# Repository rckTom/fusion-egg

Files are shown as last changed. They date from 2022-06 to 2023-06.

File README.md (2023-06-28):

# Fusion egg - An audioreactive festival totem

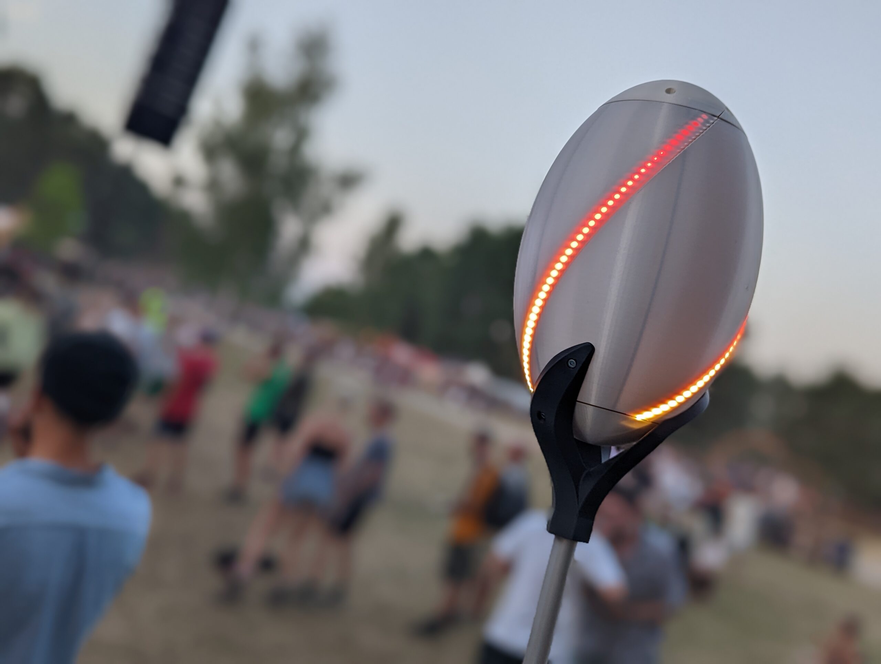
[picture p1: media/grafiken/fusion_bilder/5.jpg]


## Overview

This repository contains software and cad-files for an audioreactive festival totem. This totem is used to find ones crew at a music festival. It listens to the music, detects the beat and translates into a visual animation.

## Structure

## Build
To build your own totem you need the following tools:

- 3D-Printer (z-height min 250mm , Nozzle 0.8mm)
- Laser cutter to cut the internal skeleton of the egg
- Soldering iron

The following parts are needed:

- ESP32 microcontroller board
- Microphone MAX4466
- Accelerometer ADXL345
- WS2812 LED-Stripes (144 leds per meter), for the three stripe egg you need a little bit more than 1 meter. The six stripe egg requires more than 2 meters.
- USB-Powerbank
- Micro USB-Cabel
- Wago Connectors 221-415
- Cables
- Heat-shrink tubing
- Aluminium Tube (OD 20mm, ID 17mm, 2m long)
- 6 M4x20mm Screws
- 12 M4x15mm Screws
- 18 Heat-set inserts M4x6x6
- 3mm Plywood
- Two colors of PLA (light and dark color)
- Cable-ties

### 3D Printing
For the three stripe version you have to print the following files:
- cad_3stripes/vase.stl (Vase-Mode)
- cad_3stripes/boden.stl 
- cad_3stripes/deckel.stl
- cad_3stripes/klaue.stl

For the six stripe version the folling parts you need the files from the cad_6stripes folder.

### Laser-Cutting
cad_3stripes/lasercutter.pdf contains all parts you need to cut for the 3strip version. 

Assemble the parts with wood glue inside the vase printed part, as showed in this explosion diagramm:
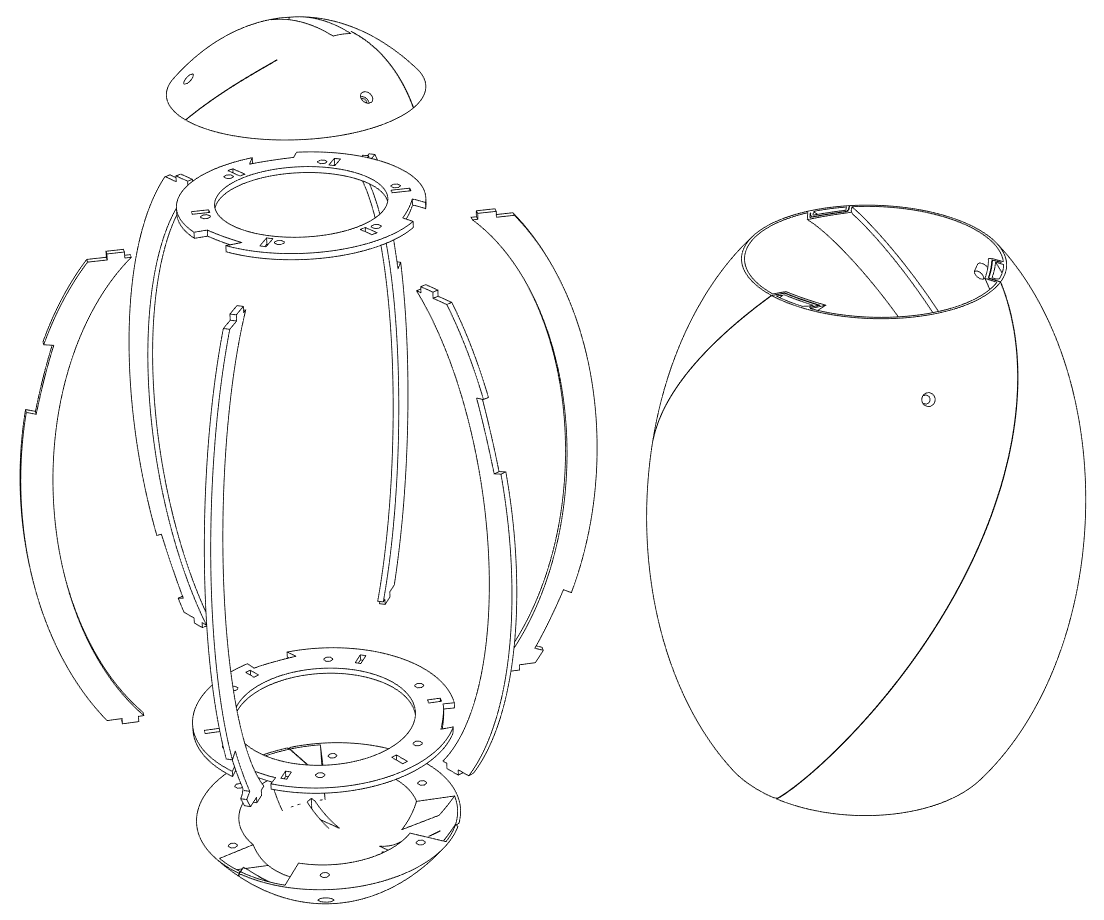
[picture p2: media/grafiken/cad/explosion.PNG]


### Electronics
Connect all electronics as showed here:
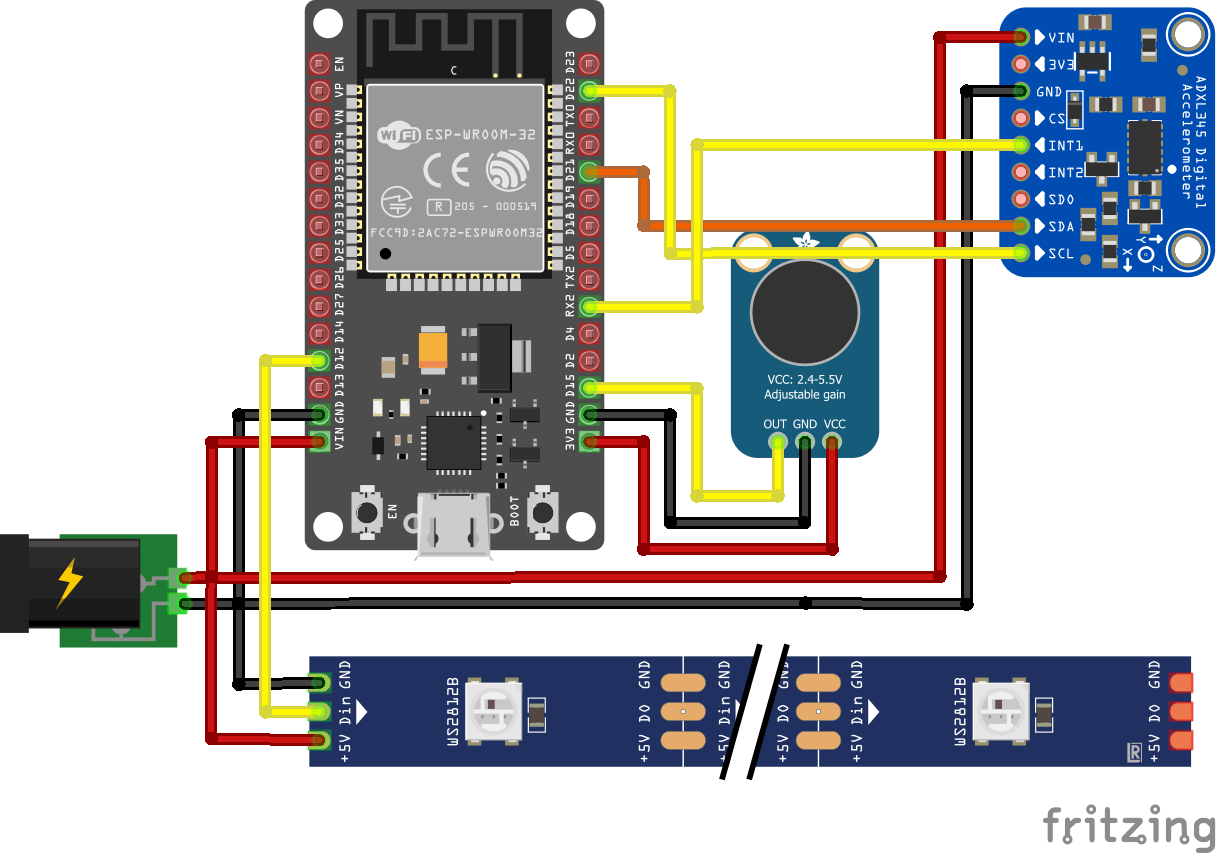
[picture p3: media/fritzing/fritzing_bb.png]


### Software
Build the sofware inside the firmware folder with PlatformIO. If you need to change the pin assignment for the leds or the microphone, you can find the definitions inside firmware/include/zauberstab.h. Don't forget to flash your eggs.

## License
All software is licensed under GPLv2. Hardware is licensed under CC BY-NC-SA. Contact us for commercial use.

## Contact
You can contact us at tom@binary-kitchen.de and buddhabrot@binary-kitchen.de

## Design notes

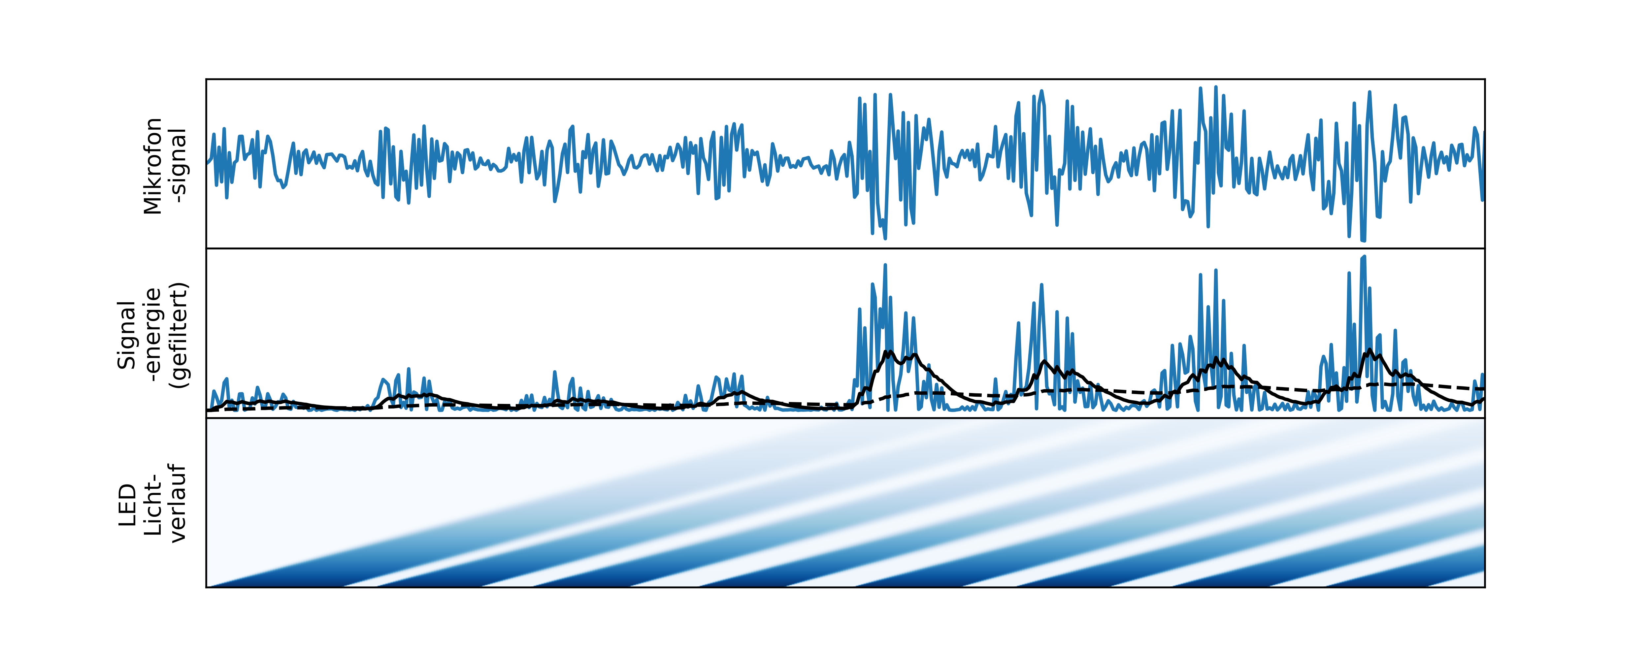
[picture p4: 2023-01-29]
media/grafiken/illustrationen/fackel.png

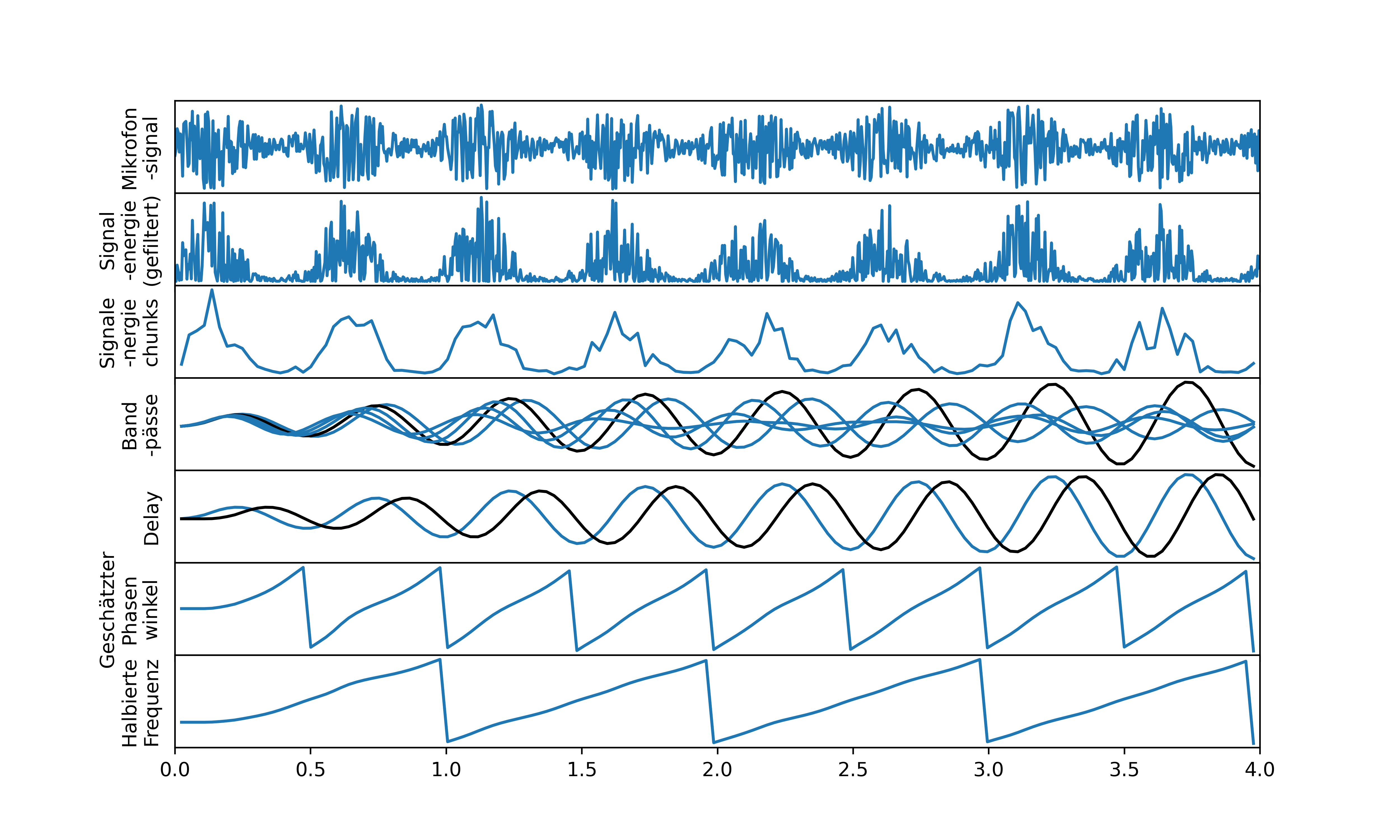
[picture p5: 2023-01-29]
media/grafiken/illustrationen/beaterkennung.PNG

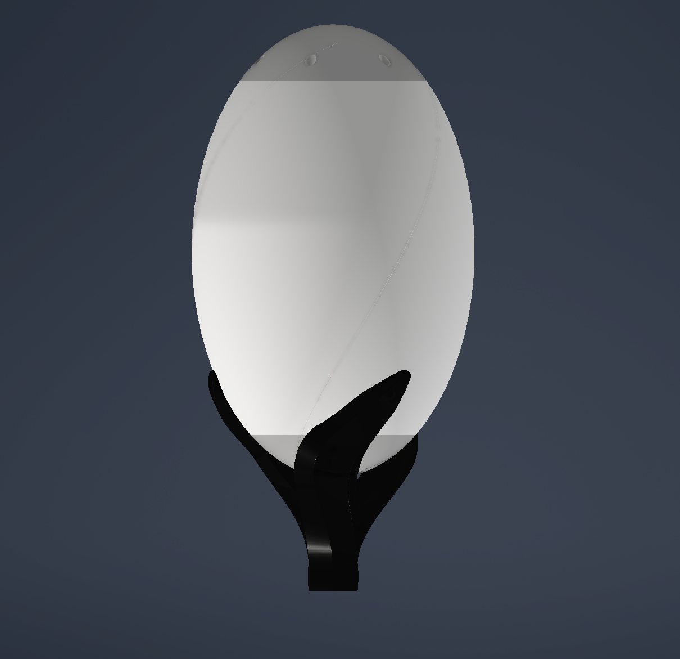
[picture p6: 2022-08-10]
media/grafiken/cad/zusammenbau3.PNG

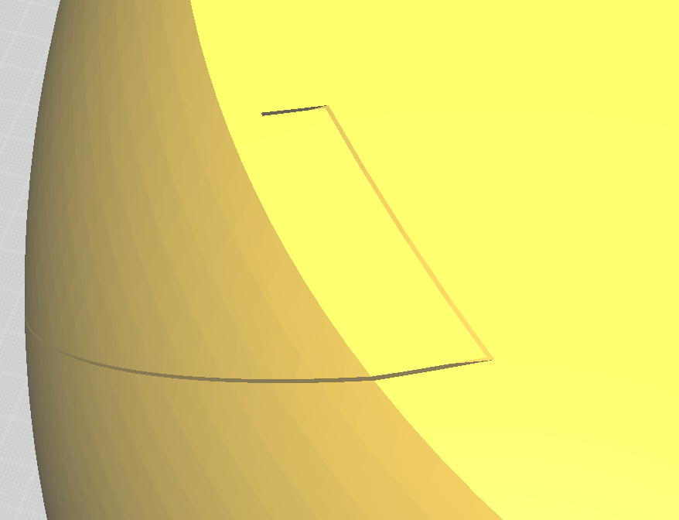
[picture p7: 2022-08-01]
media/grafiken/illustrationen/vase_cad.PNG

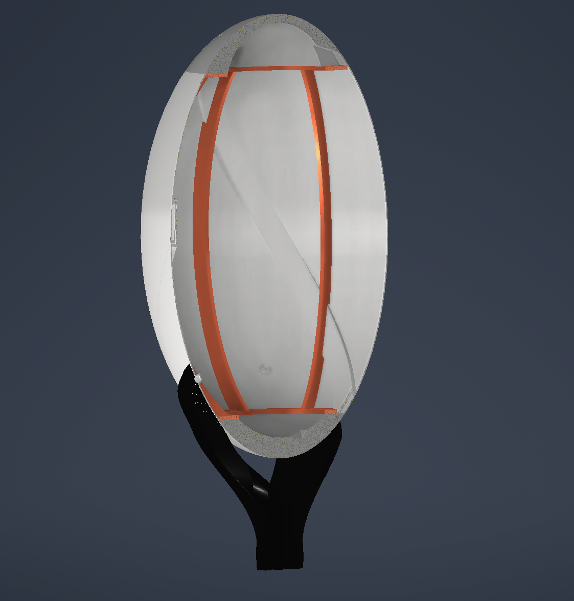
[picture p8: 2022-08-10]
media/grafiken/cad/zusammenbau4.PNG

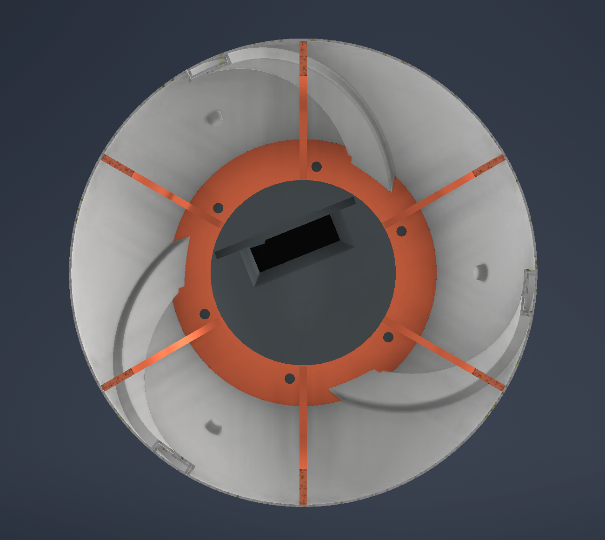
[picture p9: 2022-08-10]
media/grafiken/cad/zusammenbau2.PNG

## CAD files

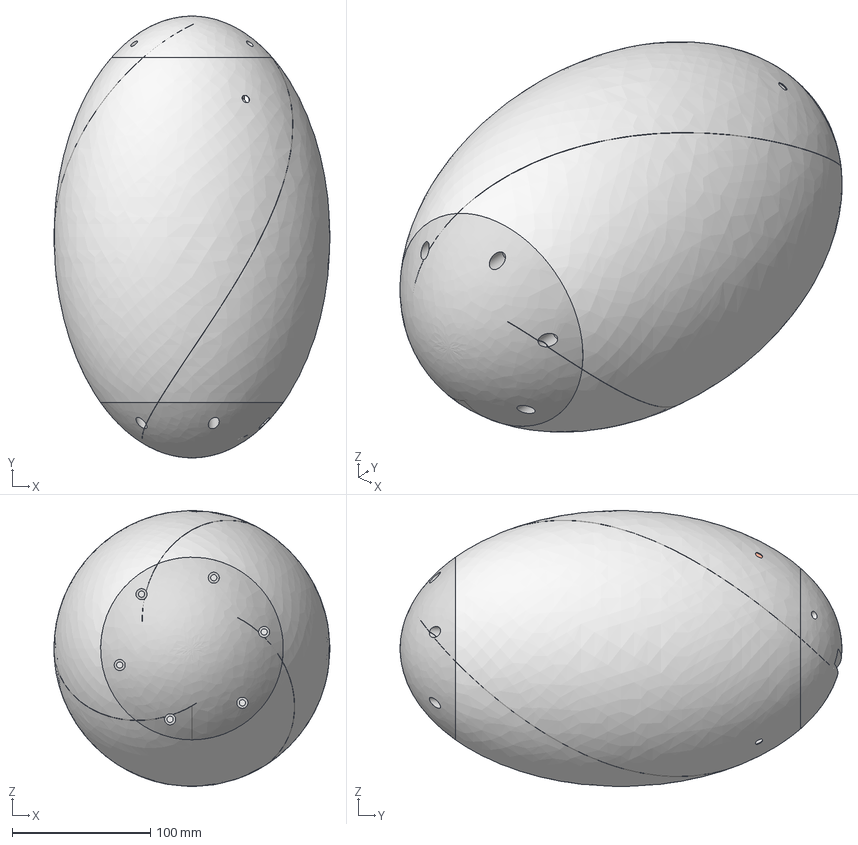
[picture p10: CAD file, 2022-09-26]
cad_3stripes/exports/assembly.stp
199.9 x 320.0 x 200.0 mm
vase_v2._tom
Spant x 3
top_centering_ring
lower_centering_ring
Spant2 x 3
deckel
boden
klaue
platte3

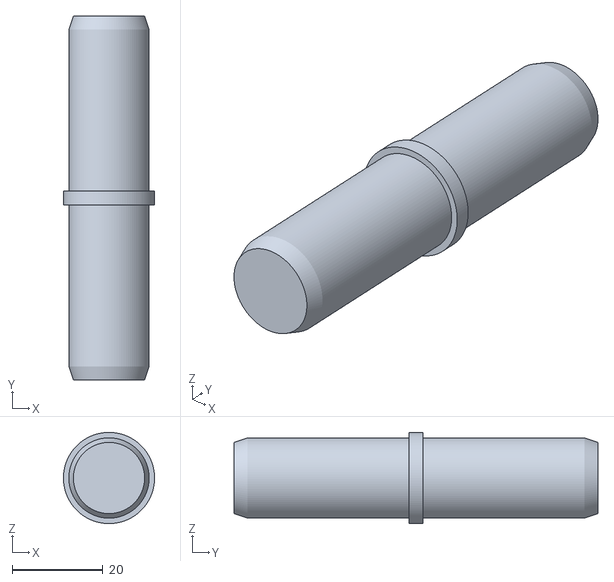
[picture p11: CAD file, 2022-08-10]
cad_3stripes/zubehoer/stange_verbinder.stl
20.0 x 80.0 x 20.0

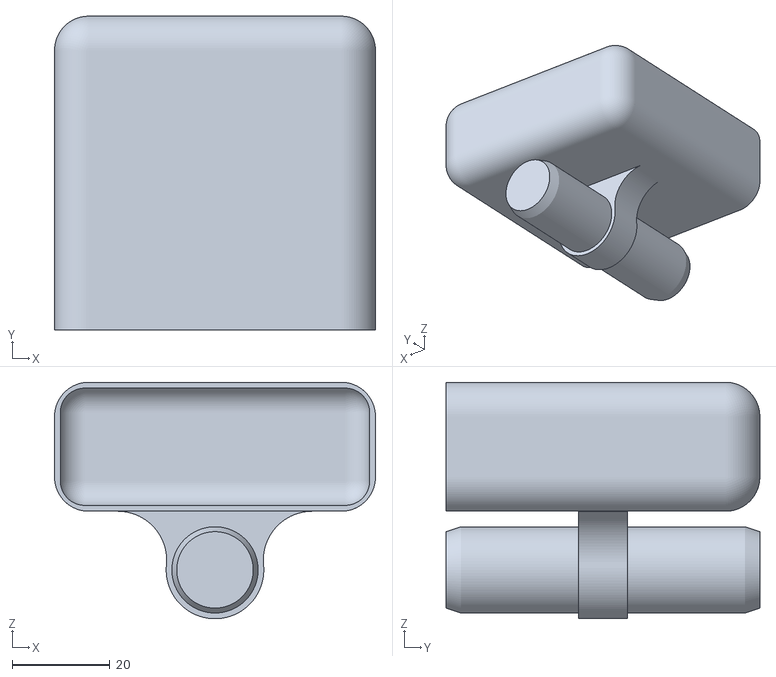
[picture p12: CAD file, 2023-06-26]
cad_6stripes/zubehoer/batteriehalter2.stl
65.7 x 64.2 x 48.4

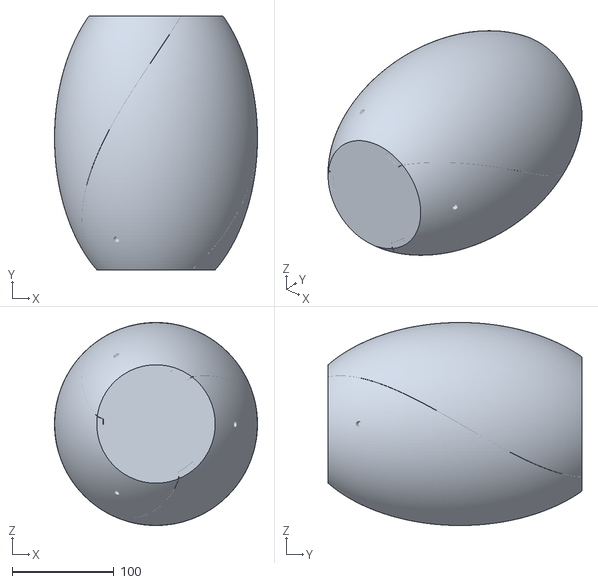
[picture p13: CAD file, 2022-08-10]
cad_3stripes/vase.stl
200.0 x 250.0 x 200.0

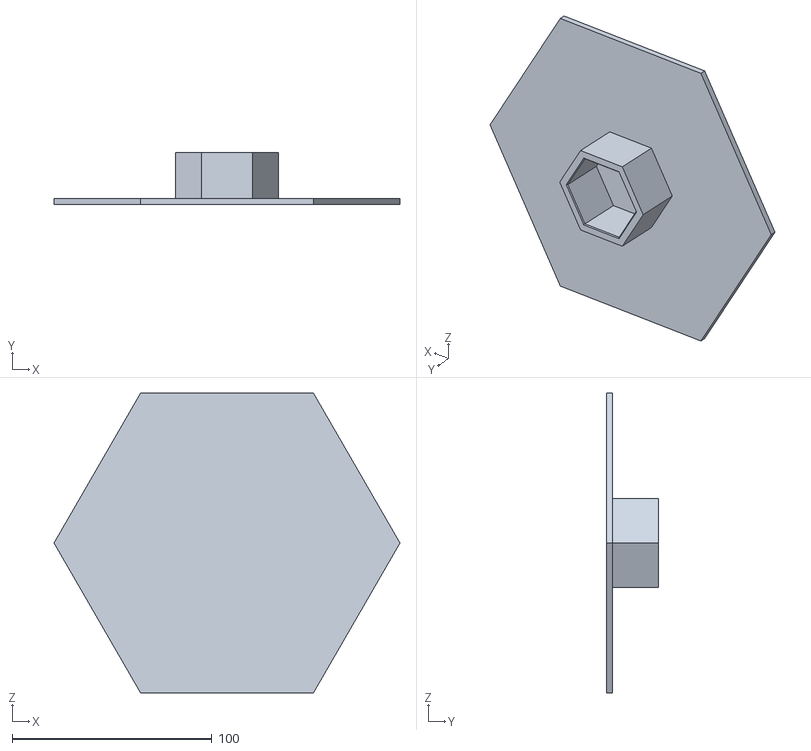
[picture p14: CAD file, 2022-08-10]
cad_3stripes/zubehoer/staender_tisch.stl
173.2 x 26.0 x 150.0

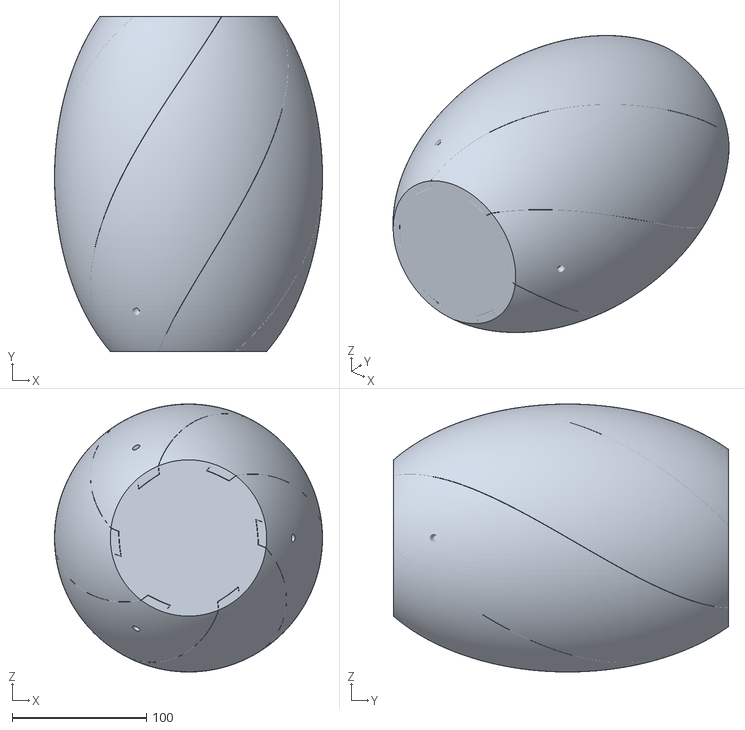
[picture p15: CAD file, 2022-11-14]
cad_6stripes/vase.stl
200.0 x 250.0 x 200.0

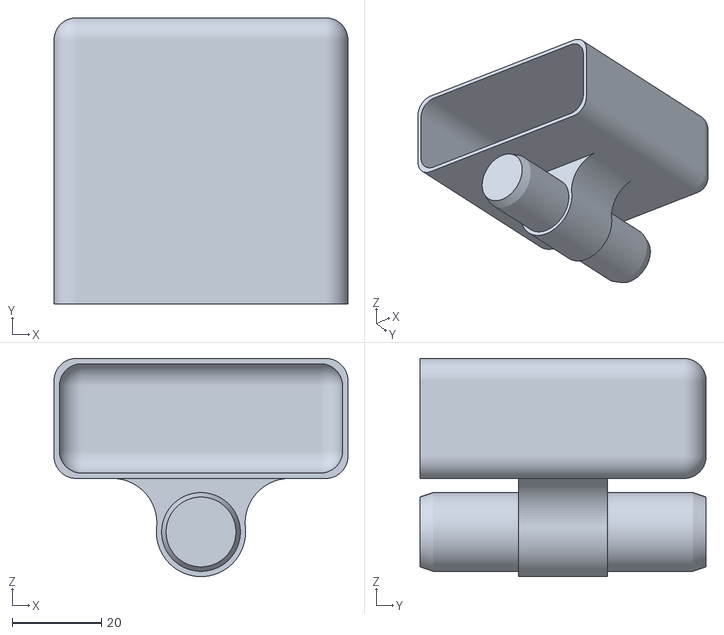
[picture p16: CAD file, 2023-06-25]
cad_6stripes/zubehoer/batteriehalter.stl
65.9 x 64.2 x 48.9

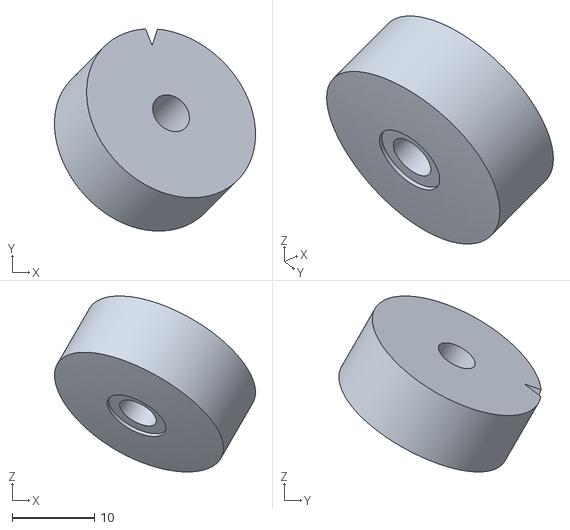
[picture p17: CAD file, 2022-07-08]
cad_3stripes/mutter-halter.stl
24.5 x 24.6 x 21.4

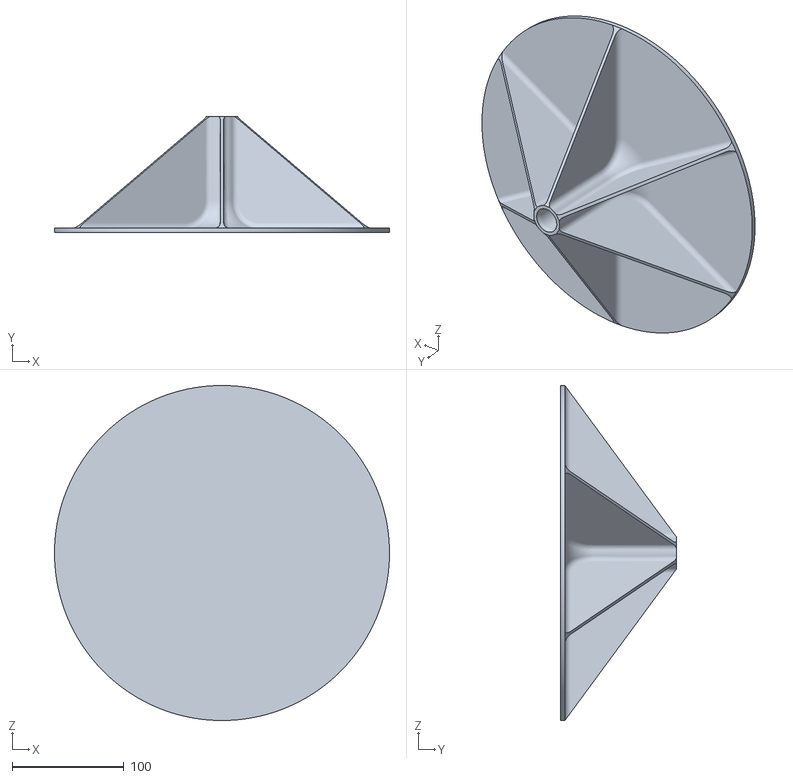
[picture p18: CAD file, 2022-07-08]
cad_3stripes/zubehoer/staender_boden.stl
300.0 x 104.0 x 300.0

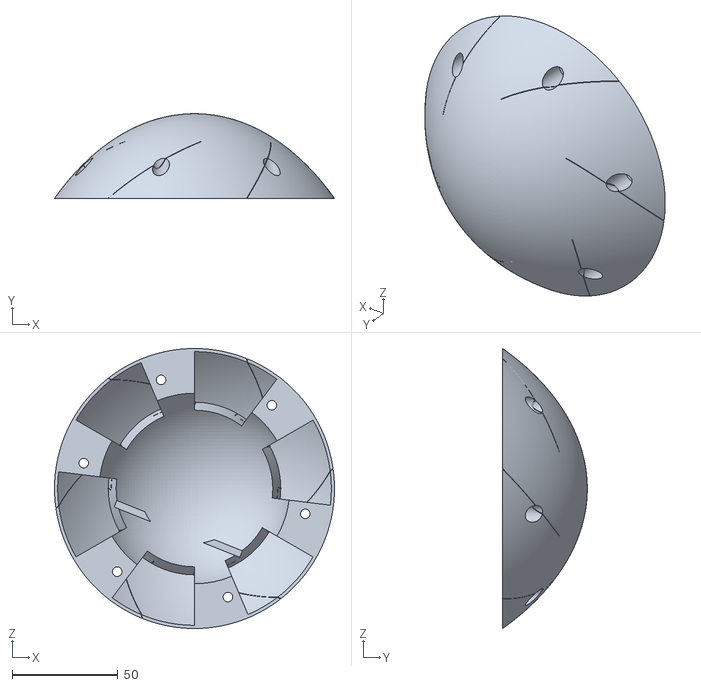
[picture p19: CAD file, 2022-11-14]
cad_6stripes/deckel.stl
132.3 x 40.0 x 132.3

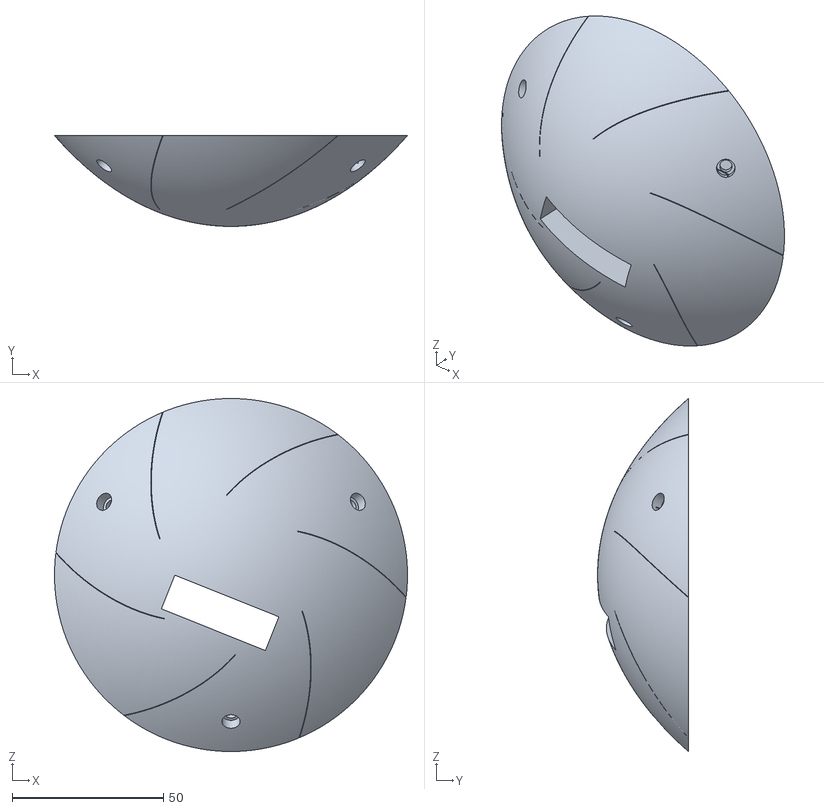
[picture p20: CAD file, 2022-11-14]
cad_6stripes/boden.stl
116.6 x 30.0 x 116.6

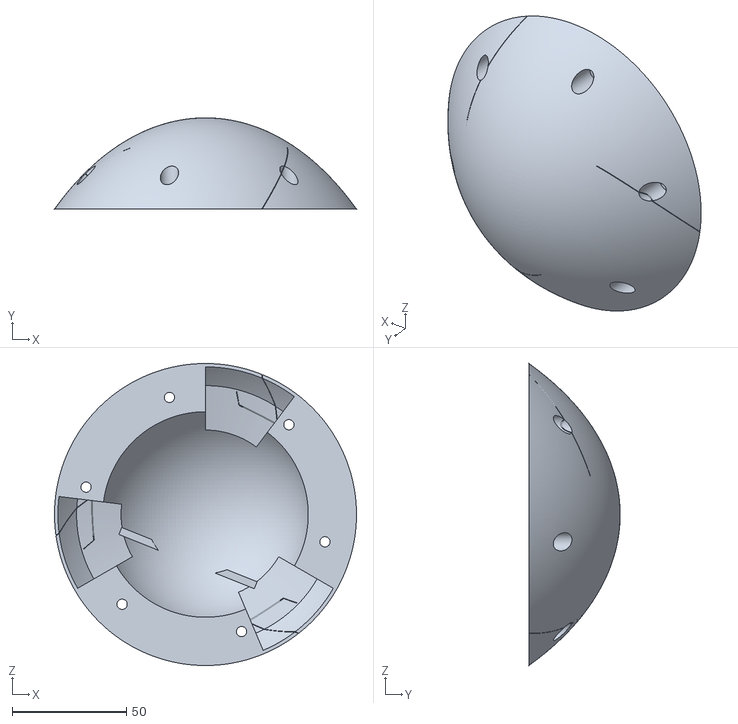
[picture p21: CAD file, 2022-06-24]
cad_3stripes/deckel.stl
132.3 x 40.0 x 132.3

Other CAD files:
cad_3stripes/lasercutter.dwg
cad_6stripes/lasercutter.dwg
cad_3stripes/OldVersions/lasercutter.0003.dwg
cad_3stripes/SpantA.ipt
cad_3stripes/SpantB.ipt
cad_3stripes/aussenhaut.stp
cad_3stripes/boden.ipt
cad_3stripes/boden.stl
cad_3stripes/deckel.ipt
cad_3stripes/platte3.ipt
cad_3stripes/ring_oben.ipt
cad_3stripes/ring_unten.ipt
cad_3stripes/vase.ipt
cad_3stripes/zubehoer/assembly.ipn
cad_3stripes/zubehoer/staender_boden.ipt
cad_3stripes/zubehoer/staender_tisch.ipt
cad_3stripes/zubehoer/stange_verbinder.ipt
cad_6stripes/OldVersions/SpantA.0002.ipt
cad_6stripes/OldVersions/SpantB.0001.ipt
cad_6stripes/OldVersions/boden.0007.ipt
cad_6stripes/OldVersions/deckel.0014.ipt
cad_6stripes/OldVersions/lasercutter.0003.dwg
cad_6stripes/OldVersions/platte3.0001.ipt
cad_6stripes/OldVersions/platte_drawing.0002.ipt
cad_6stripes/OldVersions/ring_oben.0005.ipt
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

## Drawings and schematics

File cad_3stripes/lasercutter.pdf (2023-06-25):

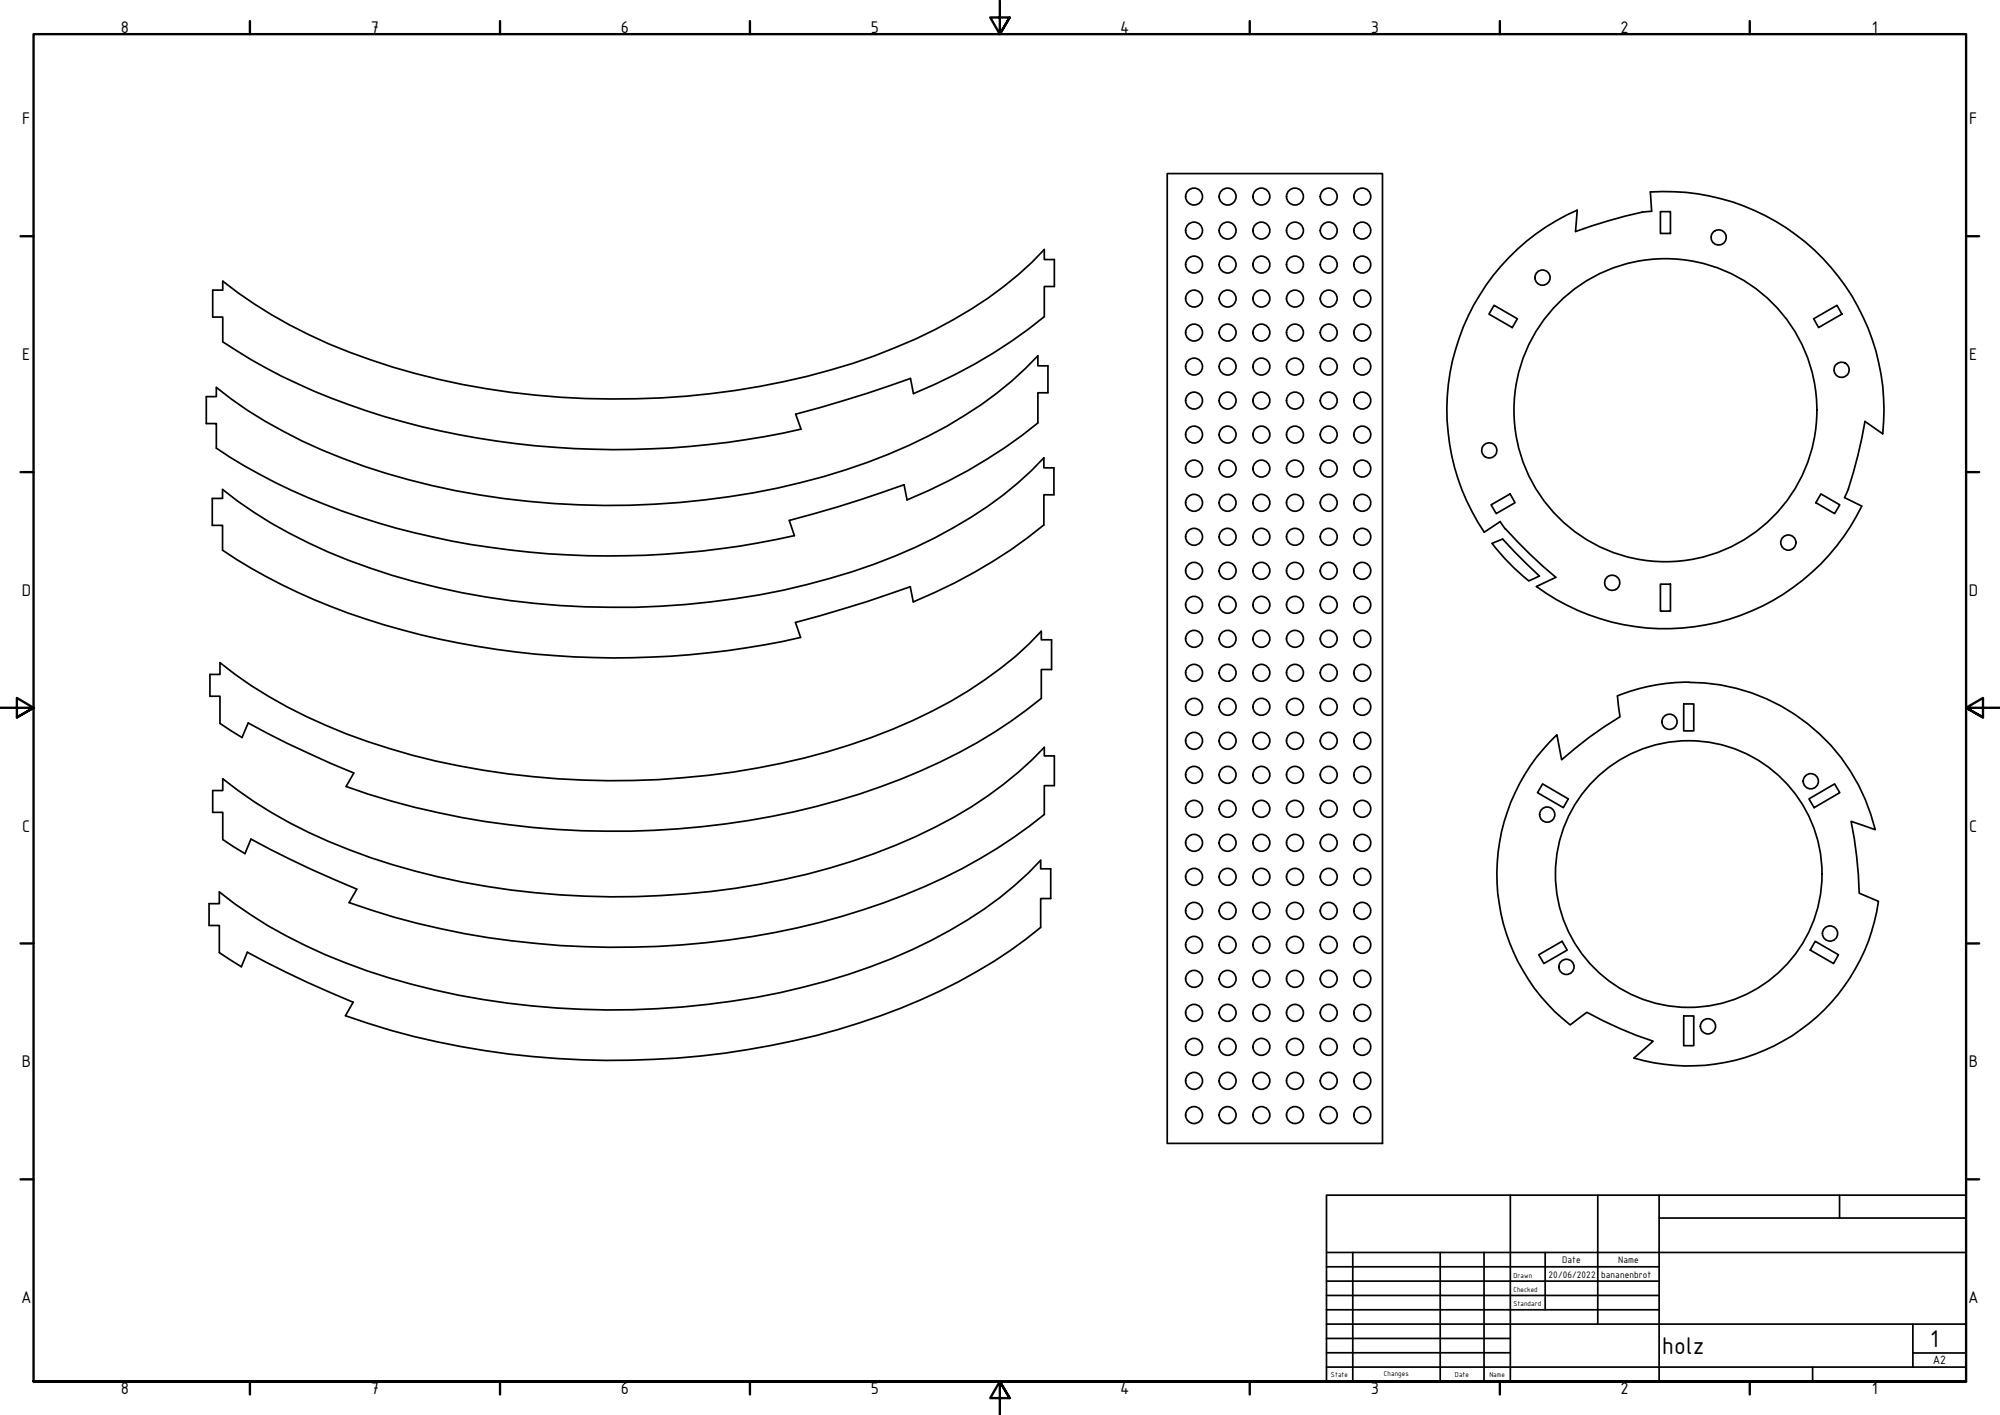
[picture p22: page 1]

Date | Name

Drawn | 20/06/2022 | bananenbrot

Checked

Standard

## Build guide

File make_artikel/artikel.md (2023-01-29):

Fusion Zauberstab
=================

# Motivation

# Konzept
- (Explosionzeichung Ei)

# 3D-Druck - Vase-Mode mal anders
> Info Vase-Mode
- Vor und Nachteile größere Düse
- Vase Mode (Abbildung, 2D Schnitt CAD-Modell)
- Druckeinstellungen

# Holzskelett
- Lasercutter (Bild Lasercutter)
- Verschraubung Boden und Deckel (Bild einpressen Einschlagmutter)

# Software-Struktur
- Verwendete Bibliotheken
    - FastLED
    - ADXL345 Bibliothek
- Aufbau des Projekts
- Apps
- Double tap
- Verwendung von Interrupts
- ESP32 Deep Sleep

# Beaterkennung
> Info: Biquad
- (Blockdiagramm)

# Fackel
- Algorithmus Feuer
- "Seeding" mit Sound
- (Blockdiagramm)

# Anleitung
- hardware
- software
- plattformIO

# Praxistest
- (Fusion Bilder)
- beaterkennung funktioniert je nach musik, fackel immer

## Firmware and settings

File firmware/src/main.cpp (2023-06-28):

/* 
 * Copyright 2023 Alexander Alber and Thomas Schmid
 * 
 * SPDX-License-Identifier: GPL-2.0
 */

#include "app.h"
#include "driver/adc.h"
#include "zauberstab.h"
#include <vector>

struct BeatDetectApp beat_detect_app
{
};

struct QuarterApp quarter_app
{
};

struct FackelApp fackel_app
{
};



std::vector<std::reference_wrapper<App>> apps = {
    std::ref<App>(beat_detect_app),
    std::ref<App>(fackel_app),
    std::ref<App>(quarter_app),
    };

static unsigned int current_app = 0;
static unsigned int next_app;
static bool init_successfull = false;
static bool sleep_active=false;

void switch_app() {
    if (!sleep_active) {
        next_app = current_app + 1;
    } else {
        sleep_active = false;
        next_app = 0;
    }

    if (next_app >= apps.size()) {
        next_app = 0;
        // Turn off leds before going to sleep
        fadeToBlackBy(leds, NUM_LEDS, 0xFF);
        FastLED.show();

        //configure wakeup source
        esp_sleep_enable_ext0_wakeup(GPIO_NUM_4, 1);
        
        //bedtime
        sleep_active = true;
        esp_deep_sleep_start();
    }

    next_app = next_app % apps.size();
}

void setup()
{
    next_app = current_app;
    if (zauberstab_init() != 0) {
        return;
    }
    Serial.begin(115200);

    init_successfull = true;
    apps[current_app].get().init();
}

void loop()
{
    if (!init_successfull) {
        return;
    }

    if (acc_has_event()) {
        String axes = myAcc.getActTapStatusAsString();
        byte intSource = myAcc.readAndClearInterrupts();

        if (myAcc.checkInterrupt(intSource, ADXL345_DOUBLE_TAP)) {
            switch_app();
        }
    }

    if (next_app != current_app)
    {
        apps[current_app].get().deinit();
        apps[next_app].get().init();
        current_app = next_app;
        fadeToBlackBy(leds, NUM_LEDS, 0xFF);
    }

    apps[current_app].get().loop();
}

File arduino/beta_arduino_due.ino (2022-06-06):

#include <FastLED.h>


//lichterkette: PWM 2
//mikrofon: A1
#define LED_PIN 2
#define NUM_LEDS 240


#define SAMPLING_FREQUENCY_BP 40
#define SAMPLING_FREQUENCY_CONTROL 1
#define Q 20.
#define PI 3.1415926535897932384626433832795
#define n_BP 20


CRGB leds[NUM_LEDS];

unsigned long sampling_period_bp = 1000000L/SAMPLING_FREQUENCY_BP;
unsigned long sampling_period_control = 1000000L/SAMPLING_FREQUENCY_CONTROL;
double energy = 0;
unsigned long last_us_bp = 0L;
unsigned long last_us_control = 0L;

float a0[n_BP];
float a1[n_BP];
float a2[n_BP];
float b0[n_BP];
//float b1[n_BP]; 
float b2[n_BP];

float a[n_BP];
float w0[n_BP];

float yy1[n_BP];
float yy2[n_BP];
float yy3[n_BP];
float yy4[n_BP];
float yy5[n_BP];
float yy6[n_BP];

float u1[n_BP];
float u2[n_BP];
float y[n_BP];
float y_fil[n_BP];

float angle;
float angle2;

double energy_fil = 800.;


float pos_target = NUM_LEDS/2;
float pos_target_filtered = NUM_LEDS/2;

int microphone_offset;
long initial_time;

int active = 15;
int candidate = 15;
int rounds = 0;




void setup() {

  Serial.begin(115200);
  
  FastLED.addLeds<WS2812, LED_PIN, RGB>(leds, NUM_LEDS);
  FastLED.setMaxPowerInVoltsAndMilliamps(5, 350);

  for(int i = 0; i < NUM_LEDS; i++)
  { int brightness = get_value(i, pos_target_filtered);
    leds[i].setRGB(brightness, brightness, brightness); }
  FastLED.show();

  long sumsamples = 0;
  for(int j = 1; j<1000; j++)
  {
    int sample = analogRead(1);
    sumsamples += sample;
    delay(1);
    if(j==500)
    {
      sumsamples = 0;
    }
  }
  microphone_offset = sumsamples/500;      
  set_filter();
  initial_time = micros();

  
}

void set_filter() {
  for(int i = 0; i < n_BP; i++)
  {
    float frequency = 1.75+i*0.033;
    
    w0[i] = 2.*PI*frequency/SAMPLING_FREQUENCY_BP;
    a[i] = sin(w0[i]/(2.*Q)); 
  
    b0[i] = a[i];
    //b1[i] = 0;
    b2[i] = -a[i];
    a0[i] = 1.+a[i];
    a1[i] = -2.*cos(w0[i]);
    a2[i] = 1.-a[i];
  }
}

int get_value(int pos, float pos0) {

  if (abs(pos0-pos) > 7)
  { return 0; }
  else
  { return (255-abs(pos0-pos)*35); }

}

void loop() {


   int sample = int(analogRead(1) - microphone_offset);

  
   energy += abs(sample)*abs(sample);
   
   if (micros() - last_us_bp > sampling_period_bp)
   {
       last_us_bp += sampling_period_bp;
       energy_fil += (energy - energy_fil) * 0.01;
      Serial.println(energy);
        for(int i = 0; i < n_BP; i++)
        {
           y[i] = (b0[i]/a0[i])*energy + 0. + (b2[i]/a0[i])*u2[i] - (a1[i]/a0[i])*yy1[i] - (a2[i]/a0[i])*yy2[i];
           u2[i] = u1[i];
           u1[i] = energy;
           yy6[i] = yy5[i];
           yy5[i] = yy4[i];
           yy4[i] = yy3[i];
           yy3[i] = yy2[i];
           yy2[i] = yy1[i];
           yy1[i] = y[i];

           y_fil[i] += (abs(y[i]) - y_fil[i]) * 0.005; //linie der scheitelpunkte
        }


       float delays = constrain( SAMPLING_FREQUENCY_BP * 0.25/(1.75+active*0.033) , 4., 6.);

       float delayed = 0;
       if (delays > 5)
       {delayed = yy5[active]*(1-delays+5) + yy6[active]*(delays-5); }
       else
       {delayed = yy4[active]*(1-delays+4) + yy5[active]*(delays-4); }

       angle = atan2(delayed , y[active]);

       if (PI < abs(angle - angle2) && abs(angle - angle2)  < 3*PI)
       { angle2 = angle + 2*PI; }
       else
       { angle2 = angle; }

       pos_target = map(angle2, -PI, 3*PI, -0.1*NUM_LEDS, NUM_LEDS*1.1);
        


       if (pos_target > pos_target_filtered)
       { pos_target_filtered += (pos_target - pos_target_filtered)*0.5; }
       else
       { pos_target_filtered = pos_target; }

       energy = 0;

       for(int i = 0; i < NUM_LEDS; i++)
       { int brightness = get_value(i, pos_target_filtered);
         leds[i].setRGB(brightness, brightness, brightness); }
       FastLED.show();
   }

   if (micros() - last_us_control > sampling_period_control)
   {          
      last_us_control += sampling_period_control;
      int argmax = -1;
      float valuemax = 0;
      for(int i = 0; i < n_BP; i++)
      {
        if(y_fil[i] > valuemax)
        {
          valuemax = y_fil[i];
          argmax = i;
        }
      }
      
      if(argmax > -1)
      {
          if(argmax == candidate)
          {
            rounds ++;              
          }
          else
          {
            rounds = 0;
            candidate = argmax;
          }
          if(rounds > 5)
          {
            rounds = 0;
            active = candidate;
          }
      }           
   }
}

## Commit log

2022-06-06 arduino sketch has to be in folder of same name
2022-06-10 first cad
    [huelle-tom.0002.ipt, huelle-tom.ipt, huelle.0005.ipt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]
2022-06-10 add dwg version
    [huelle.dwg]
2022-06-12 huelle aktualisiert
    [huelle.0005.ipt, huelle.0011.ipt, huelle.ipt]
2022-06-12 huelle weiter detailliert
    [huelle.0011.ipt, huelle.0013.ipt, huelle.ipt]
2022-06-12 huelle candidate 1
    [huelle.0013.ipt, huelle.0015.ipt, huelle.ipt]
2022-06-16 vase mit weniger abstand
    [huelle_vase.0001.ipt, huelle_vase.ipt]
2022-06-16 vase ohne surface
    [huelle_vase.0003.ipt, huelle_vase.ipt]
2022-06-16 steilere kurven und orthogonale profile
    [huelle_vase.0002.ipt, huelle_vase.0003.ipt, huelle_vase.0008.ipt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]
2022-06-16 dickere luecken
    [huelle_vase.0008.ipt, huelle_vase.0009.ipt, huelle_vase.ipt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]
2022-06-17 first draft of esp32 firmware
2022-06-17 gewinde test
    [huelle_vase.0009.ipt, huelle_vase.0010.ipt, huelle_vase.ipt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]
2022-06-17 gewindetest v2
    [huelle_vase.0010.ipt, huelle_vase.0011.ipt, huelle_vase.ipt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]
2022-06-18 add dc_cancelation filter
2022-06-18 add pt1 filter code
2022-06-18 sicherheitskopie wegen bluescreen
    [Assembly1.0002.iam, Assembly1.iam, huelle-tom.ipt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]
2022-06-18 stuetzpunkte hinzugefuegt
    [Assembly1.0002.iam, Assembly1.0006.iam, Assembly1.iam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]
2022-06-18 ei vase
    [Assembly1.0006.iam, Assembly1.0007.iam, Assembly1.iam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]
2022-06-18 step file
    [aussenhaut.stp]
2022-06-19 transience entfernt
    [vase_v2._tom.0017.ipt, vase_v2._tom.ipt]
2022-06-19 add biquad filter code
2022-06-19 add app framework
    add a framework to allow for multiple applications and switching between
    them
2022-06-19 main: blank all leds on app switch
2022-06-20 boden und deckel
    [Assembly1.0008.iam, Assembly1.0009.iam, Assembly1.iam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]
2022-06-24 boden und deckel fertig
    [Assembly1.0009.iam, Assembly1.0016.iam, Assembly1.iam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]
2022-06-24 deckel mit platz für leds
    [deckel.0010.ipt, deckel.0011.ipt, deckel.ipt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]
2022-06-25 fackel reversed und gekuerzt
    [beat_detect.cpp, fackel.cpp, main.cpp]
2022-06-25 klaue tiefer geschlitzt
    [aufhaengung.0005.ipt, aufhaengung.0006.ipt, aufhaengung.ipt]
2022-06-25 aufhaengung mit beschriftung
    [aufhaengung.0006.ipt, aufhaengung.0007.ipt, aufhaengung.ipt]
2022-06-25 add acceleration sensor
2022-06-25 radius weg
    [aufhaengung.0007.ipt, aufhaengung.0008.ipt, aufhaengung.ipt]
2022-06-26 aufhaengung mit flacheren winkeln
    [Assembly1.0016.iam, Assembly1.0018.iam, Assembly1.iam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]
2022-06-26 pt1 bug gefixed und alternative farbschemas eingestellt
    [beat_detect.cpp, fackel.cpp, main.cpp]
2022-06-26 pt1 bug gefixed und alternative farbschemata
    [beat_detect.cpp, fackel.cpp, main.cpp]
2022-06-27 everything from kitchen pc
    [mutter-halter.stl]
2022-08-04 kitchen fotos und section praxistest
2022-08-10 cad aufgeraeumt + zubehoer
    [Assembly1.0018.iam, Assembly1.iam, Spant.ipt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]
2022-09-26 step export
    [assembly.ipn, assembly.stp]
2022-09-26 step export 2
    [assembly.stp, platte2.ipt, platte3.ipt]
2022-11-14 version with 6 leds
    [SpantA.0002.ipt, SpantB.0001.ipt, SpantB.ipt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]
2023-06-25 quarter animation
    [batteriehalter.0004.ipt, batteriehalter.ipt, batteriehalter.stl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]
2023-06-26 batteriehalter finetuning
    [batteriehalter.0004.ipt, batteriehalter.0005.ipt, batteriehalter.ipt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]
2023-06-28 rename cad folders
    [SpantA.0002.ipt, SpantA.ipt, SpantB.0001.ipt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]
2023-06-28 add media folder
    [fritzing.fzz]
2023-06-28 move pin assignments to zauberstab.h
